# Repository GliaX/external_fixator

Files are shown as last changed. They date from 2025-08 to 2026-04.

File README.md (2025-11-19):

# NOT FOR CLINICAL USE - Orthopedic external fixator device

**This project is still under heavy development and not for clincal use**

## Introduction
External fixation devices experience a steep surge in need during
mass casualty and increased trauma situations. This project creates
a 3D printable external fixation kit that can be produced with
commodity 3D printers and easily available nuts, bolts, and metal parts.

## Acknowledgments
This project is heavily based on work by the Imperial College London team in producing a 3D-printed external fixator.

## Printing instructions
* PLA and ABS should not be used in production. Only PETG can be used.

## Assembly instructions
* Head of bolt is situated in the Hex trap of the rod clamp
* Put the pin clamp onto the bolt and secure with washer and nut on the side of the pin clamp

## Quality assurance
* Look at the [testing folder](testing) for instructions.

## Development
To open the CAD files, please use:
 * FreeCAD v1.1 (currently in Dev)
 * From "Addons", add the following:
   * Parametric Curves FP
   * Curves Workbench

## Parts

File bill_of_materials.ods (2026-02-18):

BOM Number: 003
Brief description of changes from the last part number: Changing printing plastic back to Petg, using different Schanz pin that was sourced in Amman
Part number production dates: Oct 27 2025
Github BOM version: 003
Quantity | Component Part Number | Component name | Dimensions | Material Grade | Approximate Cost | Source / Supplier | Comments
6 | 0925-M8-60-A270Hex | Stainless steel Hex bolt | 8mm D x 60mm L Hex | A2-70 | 6 NIS | Sinwar for Screws Factory in Gaza
6 | 0925-M8-A270HexReg | Stainless steel Hex Regular nut | 8mm D Hex | A2-70 | 2 NIS | Sinwar for Screws Factory in Gaza
6 | 0925-21-8.6-5116-A270 | Stainless steel washers | OD 21mm x ID 8.6mm x Thickness 1mm | A2-70 | 1 NIS | Sinwar for Screws Factory in Gaza
1 | 2018-316-8-300 | Stainless steel rod | 8mm D x 300mm L | 316 |  | Speitan in Gaza | Taken from older version of 3D printers
6 | 0925-5-200-1600947 | Schanz pins | 5mm D x 200mm L | 304 | 65 NIS | Medical Style Co. Ltd. / OrthoSelect
6 |  | 3D printed Rod Clamps | 8mm D | PETG
6 |  | 3D printed Pin Clamps | 5mm D | PETG
1 |  | 3D printed bar-to-bar Clamp | 8mm D | PETG

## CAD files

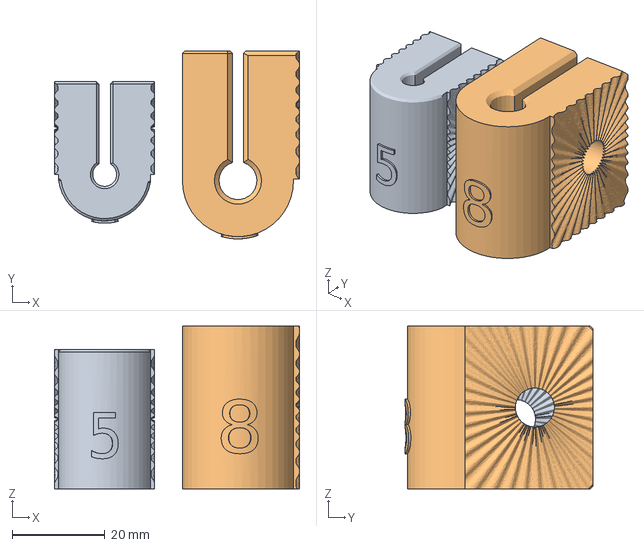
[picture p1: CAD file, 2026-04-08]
exfix x 2 PETG MK4S.3mf
52.7 x 40.4 x 35.0 mm
Pin clamp-5mm.stl
Rod clamp-8mm.stl

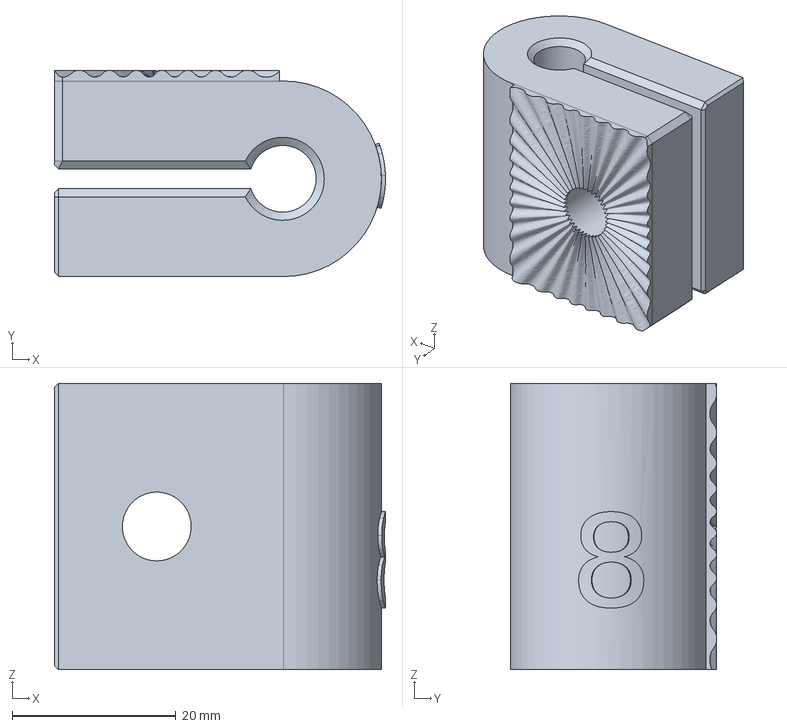
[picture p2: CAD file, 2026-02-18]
source/CAD/Bar-to-bar clamp.FCStd
40.4 x 25.2 x 35.0 mm

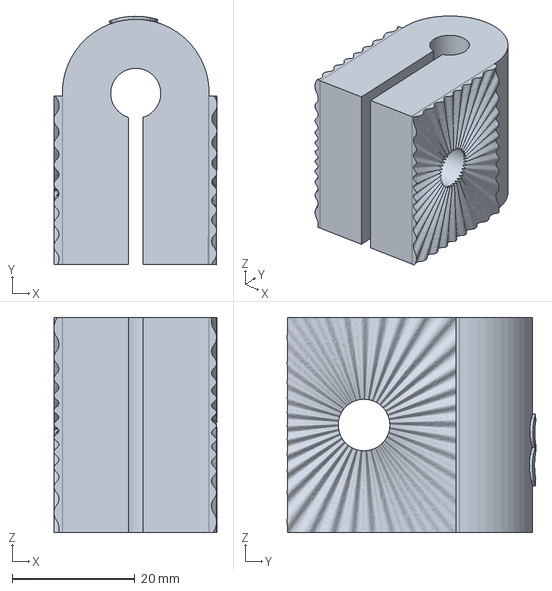
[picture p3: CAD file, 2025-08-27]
source/CAD/Rod clamp middle.FCStd
26.5 x 40.5 x 35.0 mm

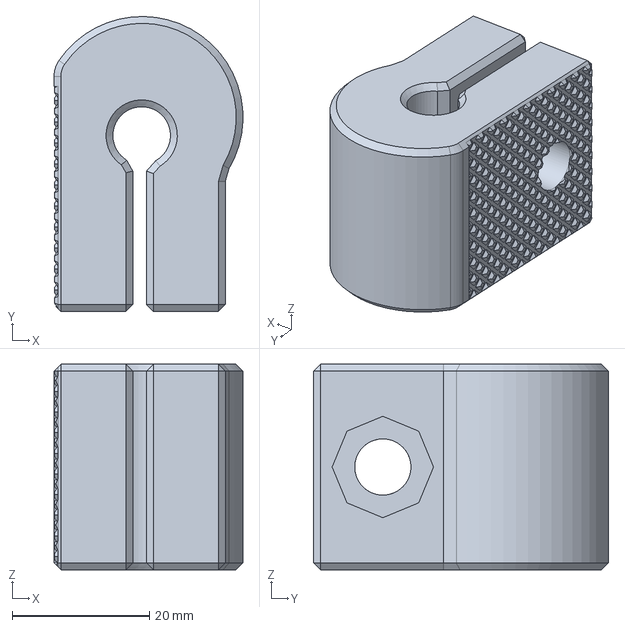
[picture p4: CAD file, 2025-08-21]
source/CAD/Rod clamp.FCStd
27.6 x 43.1 x 30.0 mm

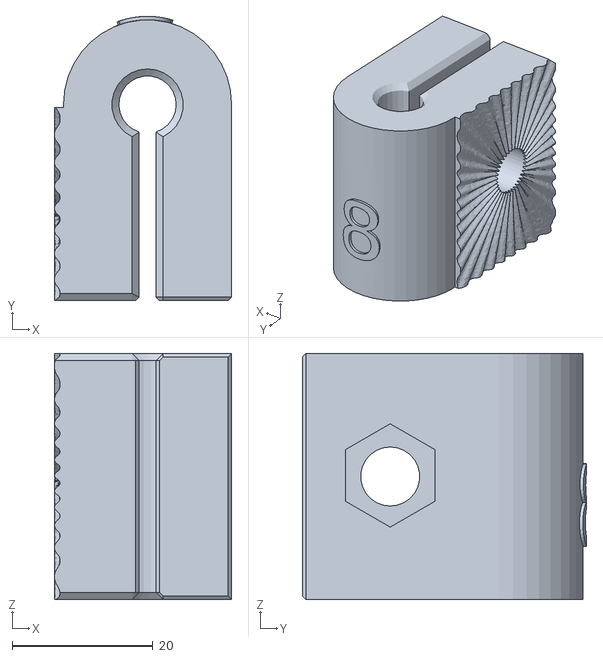
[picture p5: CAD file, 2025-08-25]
source/STL/Rod clamp-8mm.stl
25.2 x 40.4 x 35.0

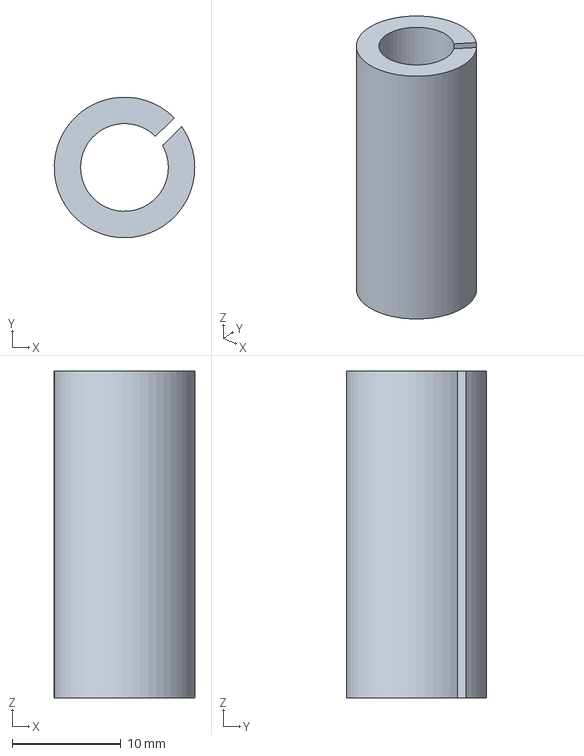
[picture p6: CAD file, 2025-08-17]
source/CAD/Connector-8mm.FCStd
12.9 x 12.9 x 30.0 mm

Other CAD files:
source/STL/Bar-to-bar clamp-8mm.stl
exfix x 2 PETG.3mf
source/STL/Rod clamp middle-9.525mm.stl
source/STL/8mm converter.stl

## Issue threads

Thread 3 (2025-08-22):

Pin Clamp: Model is not an exact match to Imperial model

tareko, 2025-08-22:
There's a little bit of plastic missing at the rounded back end. This is just a matter of fixing the first sketch, so shouldn't be an issue, but has to be done.

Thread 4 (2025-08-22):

Pin Clamp: Cylinder cut doesn't result in proper round cylinder cut and messes up mesh

tareko, 2025-08-22:
As noted, the cylinder cut at the very end causes some problem with the mesh.

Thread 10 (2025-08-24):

There is a severe shortage of metal smooth rods. Is plastic an alternative?

tareko, 2025-08-24:
There is a severe shortage of metal smooth rods. However, a local plastic producer is able to produce plastic rods out of ABS, polypropylene, and perhaps other plastics. Can polypropylene be a suitable replacement?

apopanda, 2025-08-25:
Most likely polypropylene isn't suitable, it is less stiff than many other plastics. It is slightly stiffer as compared to polyethylene (which is also a polyolefin), which is what we use with the tourniquet, but it still isn't "good". Plastics also like to deform and stretch under load, especially overtime.

A more accessible "rod" could be rebar? The diameter seems to match. No idea if it'd be suitable in the OR though, or if it's possible to sterilize it sufficiently. The ribs could also be an issue

tareko, 2025-09-04:
> Do note a potential incompatibility between OPA mentioned in issue [#14](https://github.com/GliaX/external_fixator/issues/14) and polycarbonate source: https://www.atamanchemicals.com/o-phthalaldehyde-opa_u33306/
>
> I don't know much about chemistry, other than "isopropyl and acrylics / polycarbonate is a no-no" though, so this info probably needs double checking.

Thanks for this flag. It's important to keep in mind as we move this forward. There are several other options, like the use of sodium hypochlorite (bleach), and potentially other chemicals that might serve this purpose considering that the parts are not implanted, but rather stay outside the body.

tareko, 2025-09-04:
@jenwilsonglia and I have been working hard from the Canadian side on acquiring rods that might be candidates to replace steel rods. Current candidates for testing:
* [Teflon rods](https://www.amazon.ca/gp/product/B0CMFDVJV9)
* [Nylon rods](https://www.amazon.ca/gp/product/B0CHB9WTFQ). Only nylon PA6 rods (not PA12) seemed to be available
* [Impact-resistant polycarbonate rods](https://www.mcmaster.com/products/plastics/shape~rod-1/plastic-1~/impact-resistant-polycarbonate-rods/)
* [High-strength glass-filled impact-resistant polycarbonate rods](https://www.mcmaster.com/products/plastics/shape~rod-1/plastic-1~/high-strength-glass-filled-impact-resistant-polycarbonate-rods/)
* [Rigid Glass-Filled Wear-Resistant Nylon Rods](https://www.mcmaster.com/products/plastics/shape~rod-1/plastic-1~/high-strength-glass-filled-impact-resistant-polycarbonate-rods/) - There are some other nylons at McMaster-Carr, but this was the only one that looked promising
* [Rigid Glass-Filled Wear-Resistant Easy-to-Machine Delrin® Acetal Resin Rods](https://www.mcmaster.com/products/plastics/shape~rod-1/plastic-1~/high-strength-glass-filled-impact-resistant-polycarbonate-rods/)

One small complication is that these parts are available in inch formats, and mostly in 1/4 and 1/2 inch. So we'll test against 1/2 inch and then if that works out figure out if these plastics are appropriate as 3/8, which is the closest to 10mm. It's unlikely we'll find 5/16, which is the closest to 8mm.

The suppliers we've currently identified:
* [Amazon](https://amazon.ca)
* [McMaster-Carr](https://www.mcmaster.com/)
* [Polymer Shapes](https://www.polymershapes.com/locations/london-ontario/) - Has a location in London
* [Grainger](https://www.grainger.ca) - Has a location in Sarnia

tareko, 2025-09-04:
The next step in this process will be for @Bader13012 to get spec sheets for all candidate plastic resins available in Gaza, so we don't waste our time testing materials that are simply impossible to find there.

tareko, 2025-09-10:
> Here are spec sheets from Polymer Shapes in London, ON - for

Can you get sample rods of these? 8mm x 30cm is probably what we'll use as our main text, though 10mm is also welcome.

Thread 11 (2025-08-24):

There is a severe shortage of metal smooth rods. Is threaded rod an alternative?

tareko, 2025-08-24:
As discussed in Issue #10 , there is a severe shortage of metal smooth rods. However, there is a reasonable amount of threaded rod available. Can threaded rod be a suitable replacement?

**Considerations:**
* Does it represent an increased infection risk?
* Could it cause issues with sticking to patient clothes or hurting the patient if it comes in contact with them?

tareko, 2025-09-21:
For now, I'm going to close this issue as threaded rod seems to be a non-starter since it impacts the patient experience, gets things stuck, is too hard to use, etc. For now, we'll pursue plastic rods as in Issue #10 .

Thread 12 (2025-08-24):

What is the correct bolt length?

tareko, 2025-08-24:
We presented the clinical team today with 60mm bolts. They felt this was too long and asked for 55mm. 50mm, 60mm, and 70mm are easily available in the market.

**Options:**
1. 50mm, which may end up being too short if there are any issues
2. 60mm, too long, can be cut down
3. 70mm, too long, but may be useful if adding a third connector.

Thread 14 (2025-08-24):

Make recommendations on sterilization of parts

tareko, 2025-08-24:
Currently, sterilization (technically, "high level disinfection") is done with ortho-phthalaldehyde (OPA). The brand name commonly used is Cidex. This is used internationally for disinfection of temperature-sensitive equipment. While not technically sterile, I believe this process is enough for our purposes for a device that is in any case going to be non-sterile after installation.

Here's a [company overview](https://www.asp.com/sites/default/files/pdf/CIDEX%20OPA%20Wall%20Chart%20AP-2000361.pdf) of the procedures.

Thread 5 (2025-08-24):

Tightening nut/bolt aganst pin clamp causes wear and plastic flakes to fall on patient

Bader13012, 2025-08-24:
عند استخدام الأطباء لتثبيت القطع البلاستيكية مع بعضها بواسطة البرغي والصامولة كانت القطع البلاستيكية تتأكل من الطرف الذي نستخدمة للربط
حيث انها كانت تسقط على قدم المريض
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

Bader13012, 2025-08-24:
احد الحلول المقترحه انه نحط روندلة تفصل بين البلاستك والبرغي

tareko, 2025-08-24:
Proposed solution sounds reasonable and was suggested by surgical team as well.

aclark17, 2025-08-24:
Our original design didn't have the locking teeth on both sides to prevent this issue (however in testing, the bolt head/washer still bites into the material due to the forces necessary for clamping and the limited mechanical strength of the material).

We changed to teeth on both sides as, in our testing, while crushing of the teeth was encountered, we didn't experience any plastic flakes falling off the clamp. This was also to enable more complex clamp assemblies and ensure incorrect assembly was avoided.

Is there any possibility the teeth were damaged/scraped by the tools used to tighten? We used a socket wrench, but I can imagine an adjustable wrench might bite into the surface if not held perfectly parallel.

tareko, 2025-08-24:
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

The teeth were not damaged. When recreating the issue, even very careful application results in the issue, as it's the head of the bolt (or nut as I understand you guys prefer) that does the flaking. I'll post photos when they're available of the plastic flakes. The photo above is a sample we had, but this phenomenon was clearly identified on the model on the patient (PETG plastic with perfect fit non-adjustable angled wrench).

tareko, 2025-08-24:
Here's an idea for how this can be resolved. We were discussing insetting the washer, but that would take valuable contact space when it's an interface contact. Similarly, we discussed a smaller washer, however that would result in plastic that could be impacted by the wrench head, which is about 2mm thick.

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

tareko, 2025-08-24:
Aha, interesting. No, we didn't use a washer and missed that part of the design. Is the washer spec'd as well?

angusclark94, 2025-08-24:
Ah okay, that would explain it.

ISO 7089 Washer, M8
Should be 16mm OD, 1.6mm H

tareko, 2025-08-27:
I'm going to close this issue with pull #9 requiring the 20mm washers.

Closed 2025-08-27.

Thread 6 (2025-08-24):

Rod clamp should allow pin clamps on both sides

tareko, 2025-08-24:
Currently, the rod clamp has a nut trap on one side and an interface on the other side. Sometimes, surgeons might want the option to place Schanz pins on both sides of the rod clamp.

tareko, 2025-08-27:
Reviews requested in PR #19 , which executes this piece.

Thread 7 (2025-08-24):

Nut trap may be redundant

tareko, 2025-08-24:
If we proceed with Issue #6 , then the nut trap should be removed and replaced by another metal washer as per Issue #5

aclark17, 2025-08-24:
Adding some background, the nut trap was added as a design requirement was to minimise the number of tools necessary to tighten the clamp, and to reduce the number of hands needed to hold components during the tightening process.

tareko, 2025-08-24:
This makes perfect sense. The issue is that the nut trap makes the unit asymmetrical and makes it relatively impossible to have a pin clamp on both sides, which is a situation that arose today for the tibia he was working on.

tareko, 2025-08-24:
Is the right answer here to have two separate versions? One with interfaces on both sides, and one with a nut trap on one side and an interface on the other?

tareko, 2025-08-27:
Closing this issue, as we've concluded that two separate versions are what's needed here to reduce tools in the most common use case (interface only on one side). Thank you everyone for a great discussion!

Closed 2025-08-27.

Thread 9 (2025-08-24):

Bill of materials should be added to repository

tareko, 2025-08-24:
The bill of materials is at this point simple, but should be included in the repository

tareko, 2025-08-25:
Merge of pull request #18 now closes this issue.

Closed 2025-08-25.

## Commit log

2025-08-17 Add some printing files
    [8mm converter.stl, Connector-8mm.FCStd, exfix x 2 ABS.3mf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]
2025-08-21 Add FreeCAD rod clamp based on original design
    [Rod clamp.FCStd]
2025-08-21 Move source files to more rational places
    [8mm converter.stl, Connector-8mm.FCStd]
2025-08-22 First version of new pin clamp
2025-08-22 STLs of various sizes of pin clamps
2025-08-24 Adjust with new models
    [exfix x 2 ABS.3mf, exfix x 2 PETG.3mf]
2025-08-25 First attempt at a bill of materials
    [bill_of_materials.ods]
2025-08-25 Reviewed and fixed as per @bader13012's recommendations
    [bill_of_materials.ods]
2025-08-25 Updated version of Rod Clamp as per IC's latest
2025-08-25 First draft of version 2 of rod clamp
    [Rod clamp-8mm.stl]
2025-08-27 Add middle connector piece
    [Rod clamp middle-9.525mm.stl, Rod clamp middle.FCStd]
2025-08-27 Reflect bill of material change needed if using middle connector pieces
    [bill_of_materials.ods]
2025-08-27 Added stainless steel washers
    [bill_of_materials.ods]
2025-08-27 Each bolt needs 2 washers, not one
    [bill_of_materials.ods]
2025-09-24 Added a simplified version of the current rod clamp design (no sunrays) with FEM analysis of the force / torque generated by clamping
2025-11-10 Updating BOM
    BOM 003 - Petg, regular nuts, and sourced Schanz pins
    [bill_of_materials.ods]
2025-11-11 Delete exfix x 2 ABS.3mf
    ABS is not being used for this project
    [exfix x 2 ABS.3mf]
2025-11-11 Delete Canada - exfix x 2 ABS.3mf
    ABS is not being used on this project
    [Canada - exfix x 2 ABS.3mf]
2025-11-24 Add bar-to-bar connector as per Issue #30
    [Bar-to-bar clamp-8mm.stl, Bar-to-bar clamp.FCStd, bill_of_materials.ods]
2025-12-12 uploading 3mf file with MK4S settings
    MK4S settings with 0.3mm layer height
    [exfix x 2 PETG MK4S.3mf]
